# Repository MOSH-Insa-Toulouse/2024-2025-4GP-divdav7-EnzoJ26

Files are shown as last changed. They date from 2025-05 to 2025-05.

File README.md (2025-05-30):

2024-2025-4GP-HILLAH-JACQUET
---
## Sommaire 
   - [I) Contexte et objectifs du projet](#I-Contexteetobjectifsduprojet)
   - [II) Capteur à base de crayon graphite](#II-Capteuràbasedecrayongraphite)
   - [III) Electronique Analogique](#III-Electroniqueanalogique)
   - [IV) KiCad et PCB](#IV-KiCadetPCB)
   - [V) Arduino](#V-Arduino)
   - [VI) Application Mobile](#VI-ApplicationMobile)
   - [VII) Banc de Test](#VII-BancdeTest)
   - [VIII) Datasheet](#VIII-Datasheet)

---

## I) Contexte et objectifs du projet

L'objectif de ce projet est de réaliser un capteur low-tech à base de graphite sachant que les recherches ont démontré les nombreux avantages de l'utilisation de ce matériau. L’électronique à base de papier gagne en popularité parmi les ingénieurs grâce à sa facilité d’approvisionnement, sa simplicité de fabrication et son faible coût.<br>
Pour ce faire, nous avons mis en place la réalisation de tous les processus de fabrication d'un shield PCB que nous avons ensuite connecté à une carte Arduino.<br>
Notre PCB contient 6 composants différents : une jauge de contrainte, un flex sensor, un écran oled, un encodeur rotatoire, un potentiomètre digital et un module Bluetooth. À noter que nous n'avons pas utilisé le servo-moteur qui faisait partie des composants disponibles à implémenter.<br>
La carte Arduino fonctionne avec un code que nous avons implémenté en s'inspirant grandement des codes qui étaient disponibles en open-source.<br>
Nous avons ensuite réalisé une application mobile connectée au module bluetooth afin d'acquérir les données renvoyées par nos capteurs sur le téléphone.<br>
Nous avons évalué le capteur sur un banc de test avant de conclure par la datasheet de notre capteur.<br>
À la fin de la lecture de ce github, vous devriez savoir quel capteur choisir entre le graphite et le flex ;) . <br>

# Livrables

- PCB shield pour arduino uno <br>
- Code arduino <br>
- Banc de test du capteur <br>
- Application android qui fonctionne par bluetooth <br>
- Datasheet <br>

# Matériel utilisé

-Résistances: 1x1kΩ, 1x10kΩ, 2x100 kΩ, 1x47kΩ <br>
-Potentiomètre digital MCP41050 <br>
-Capacités: 3x100nF et 1x1µF <br>
-Arduino Uno <br>
-Capteur graphite à partir d'un support papier et d'un crayon <br>
-Flex Sensor <br>
-Encodeur rotatoire Keyes KY-040 <br>
-Ecran OLED 128x64 <br>
-Module Bluetooth HC-05 <br>
-Amplificateur opérationnel LTC1050 <br>

## II) Capteur à base de crayon graphite

Ce capteur low-tech utilise la théorie de la percolation au sein d’un système granulaire constitué de nanoparticules de graphite.<br>
Nous déposons une fine couche de graphite sur la feuille de papier ce qui présente un réseau percolé caractéristique. Dans ce réseau, le transport des électrons entre les nanoparticules est basé sur le mécanisme de l’effet tunnel.<br>
Lors de l'application de déformations en tension, le réseau percolé se trouve directement étendu. Cette déformation entraîne une augmentation de la distance effective entre les particules de graphite au sein du réseau. Une partie des chemins de percolation sont par conséquent rompus. Ainsi, la conduction du matériau diminue, donc la résistance de la couche de graphite augmente.<br>
Inversement, lors de l’application de déformations en compression, le réseau percolé se trouve directement comprimé. Cette déformation entraîne une diminution de la distance effective entre les particules.<br> 
Ainsi, de nouveaux chemins de percolation sont créés, la conduction du matériau augmente, soit la résistance de la couche de graphite diminue.

Voici un schéma explicatif de ces phénomènes:

<p align="center">
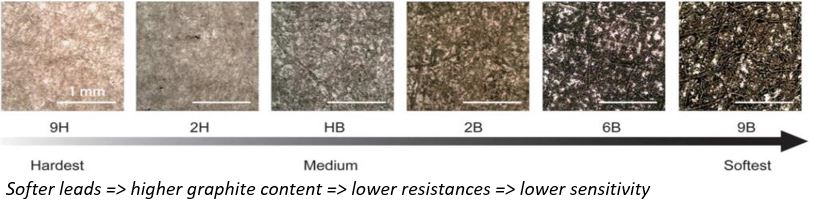
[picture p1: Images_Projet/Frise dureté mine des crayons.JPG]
Frise des duretés

<br>
<i>Sensibilité et Résistance en fonction de la dureté des mines</i>
</p>

Une jauge de contrainte est un circuit résistif dont la résistance varie en fonction de sa déformation. Donc en mesurant les variations de résistance de la jauge, nous en avons déduit la contrainte et la déformation appliquées.<br>
Notre jauge de contrainte est alimentée par une tension régulée de 5V d'une carte Arduino UNO.
<br>
Voici ci dessous le schéma d'un modèle de capteur graphite. Dans notre projet, nous avons utilisé les crayons de dureté 2H ; 2B ; HB.

<p align="center">
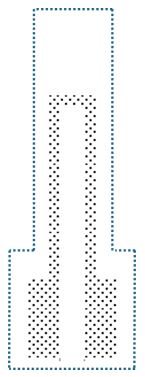
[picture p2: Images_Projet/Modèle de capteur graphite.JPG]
Figure 1 - Capteur à jauge de contrainte à base de crayon graphite

<br>
<i>Capteur à jauge de contrainte à base de crayon graphite</i>
</p>

## III) Electronique Analogique

Ce capteur graphite possède une résistance variable de l'ordre du GΩ. Le courant généré lorsque l'on applique une tension de 5V aux bornes du capteur est très faible.<br>
Pour obtenir un signal exploitable nous devions l'amplifier. Pour ce faire, nous avons utilisé un montage transimpédance constitué d'un amplificateur opérationnel.<br>
Pour cela nous avons dans un premier temps effectué une simulation électronique du capteur et de ce montage transimpédance sous LTSpice. Voici ci-dessous le montage réalisé sous LTSpice. Pour notre montage nous avons choisi l'AOP LTC1050 prenant en entrée un courant faible (de l'ordre d'une dizaine de picoampère).

<p align="center">
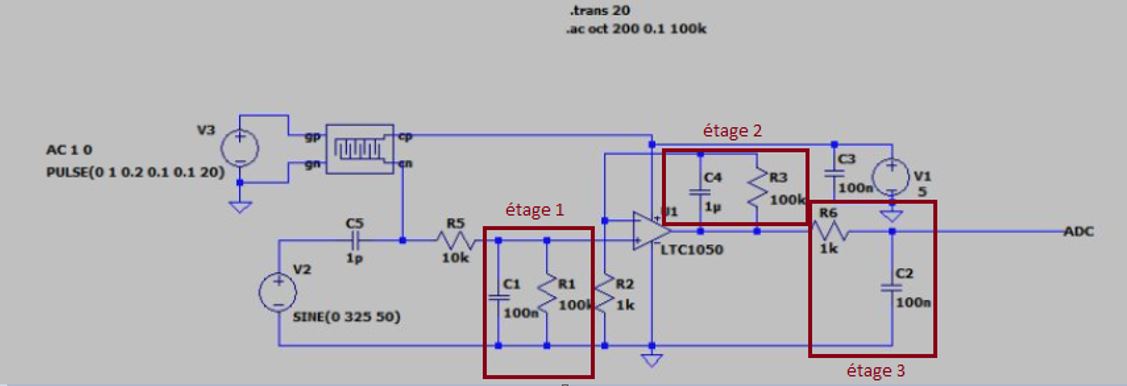
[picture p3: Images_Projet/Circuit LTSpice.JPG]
Circuit amplificateur réalisé dans LTSpice

<br>
<i>Circuit amplificateur réalisé dans LTSpice</i>
</p>
<br>
Ce circuit amplificateur contient 3 filtres passe bas passifs, dont nous avons pu tester le bon fonctionnement.<br>
<br>
- Le premier étage a une fréquence de coupure de 16 Hz, il permet de filtrer les bruits du courant en entrée. Nous avons testé ce premier étage pour vérifier que la fréquence de coupure soit la bonne.
<br>
</p>

<p align="center">
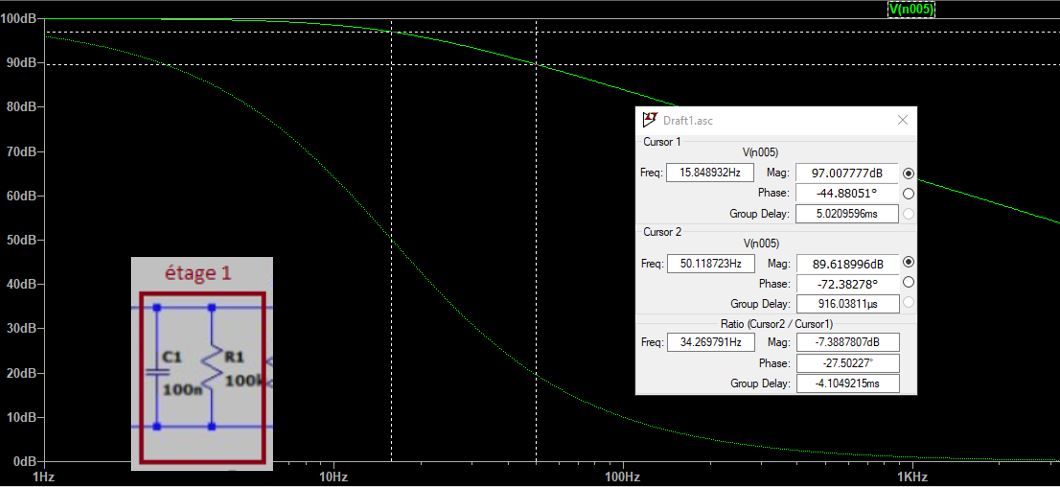
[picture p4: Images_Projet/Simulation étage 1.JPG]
Simulation de l'étage 1 dans LTSpice

<br>
<i>Simulation de l'étage 1 dans LTSpice</i>
</p>
En effet la fréquence de coupure est la bonne.
<br>
- Le second étage a une fréquence de coupure de 1,6 Hz. Il permet de filtrer la composante de bruit du réseau électrique: le bruit à 50 Hz.
<br>
</p>
<p align="center">
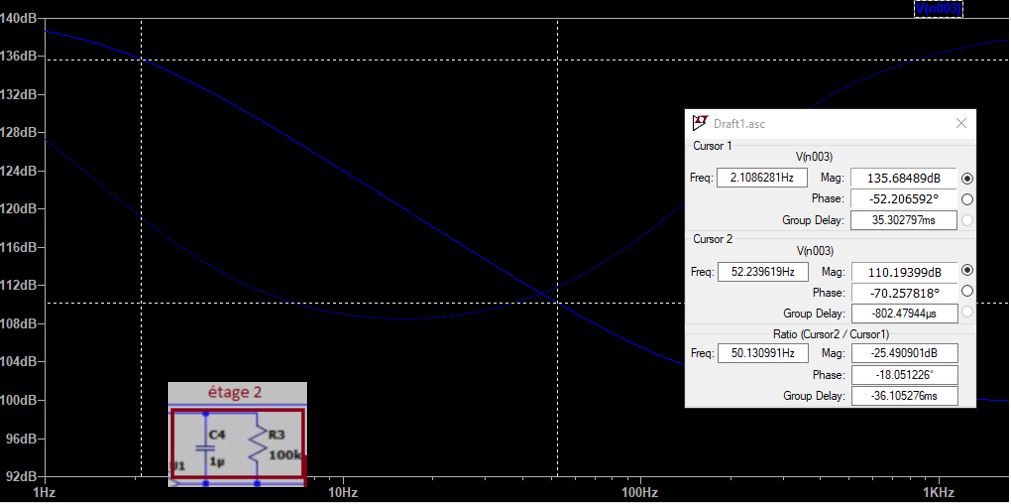
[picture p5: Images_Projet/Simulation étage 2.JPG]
Simulation de l'étage 2 dans LTSpice

<br>
<i>Simulation de l'étage 2 dans LTSpice</i>
</p>
La fréquence de coupure est de 2,1Hz alors que celle attendue est de 1,6Hz, ce qui reste dans les plages de fréquences attendues, donc nous la validons.
<br>
- Le dernier étage a une fréquence de coupure à 1,6 kHz qui permet d'atténuer le bruit provenant lors du traitement électronique.
<br>
</p>
<p align="center">
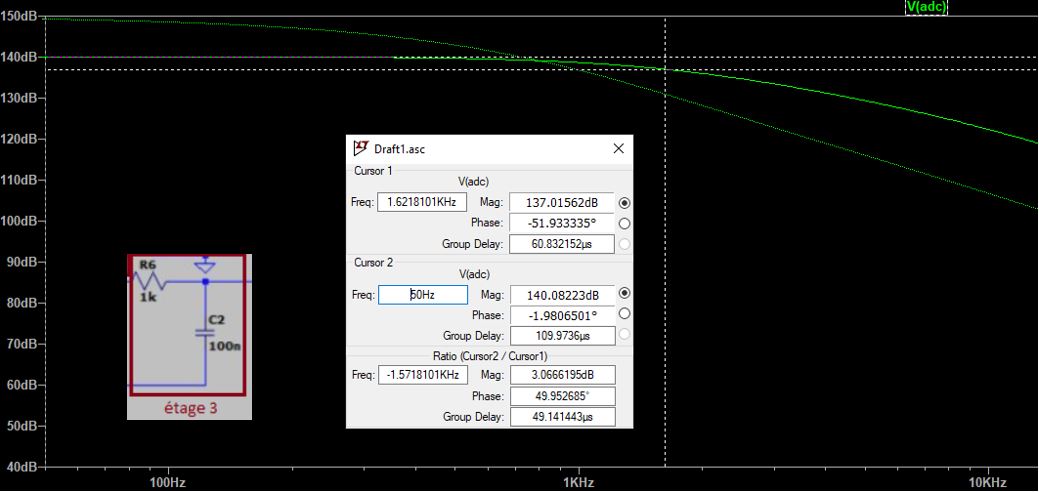
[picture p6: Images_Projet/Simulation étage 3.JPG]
Simulation de l'étage 3 dans LTSpice

<br>
<i>Simulation de l'étage 3 dans LTSpice</i>
</p>
En effet la fréquence de coupure est la bonne.
<br> 
Cette simulation nous permet de confirmer que l’arduino pourra bel et bien mesurer le signal de sortie car il sera d’environ 1V.

## IV) KiCad et PCB

Avant d'imprimer le PCB et de souder nos différents composants, nous avons dessiné les schémas électroniques, réalisé les composants électroniques et créé le PCB sur KICAD. Cette étape est importante car elle permet de prévisualiser le PCB, vérifier que tous les composants tiennent sur le PCB et ainsi de le sortir. Elle permet également de créer les différents routages de pistes. 

<p align="center">
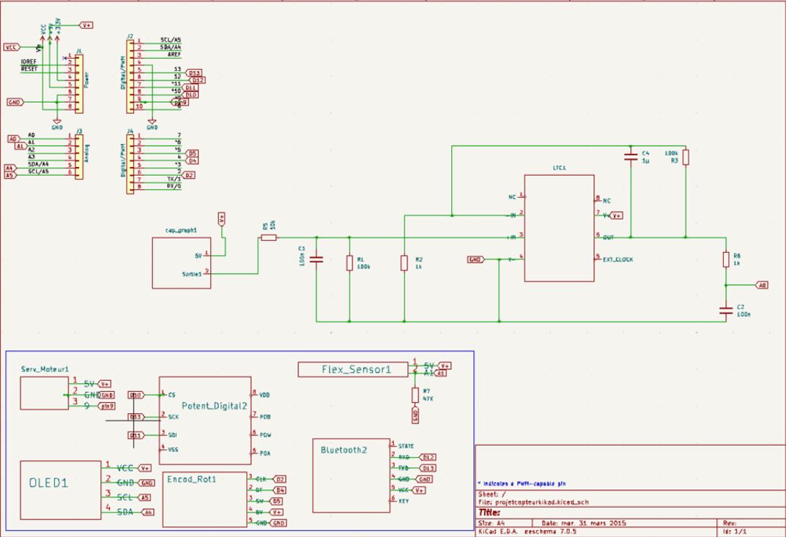
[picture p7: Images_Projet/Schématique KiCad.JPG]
Schémas électroniques

<br>
<i>Schémas électroniques</i>
</p>

<p align="center">
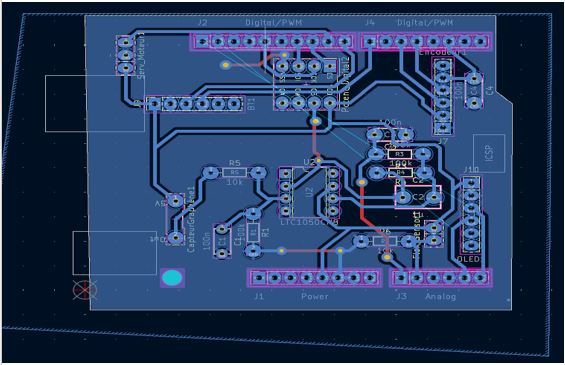
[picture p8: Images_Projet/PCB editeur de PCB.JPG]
Création du PCB et des différentes empreintes sur KiCad

<br>
<i>Création du PCB et des différentes empreintes sur KiCad</i>
</p>

<p align="center">
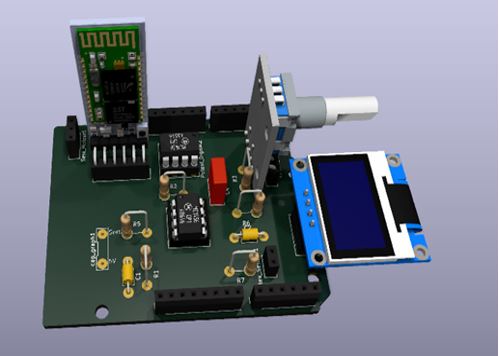
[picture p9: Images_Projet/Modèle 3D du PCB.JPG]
Visualisation 3D du PCB

<br>
<i>Visualisation 3D du PCB (idéale)</i>
</p>
<br>
Lorsque la disposition de nos différents composants électroniques était terminée suite au routage des pistes, nous avons pu imprimer le PCB, le percer et y souder les différents composants.
<br>
<br>
<p align="center">
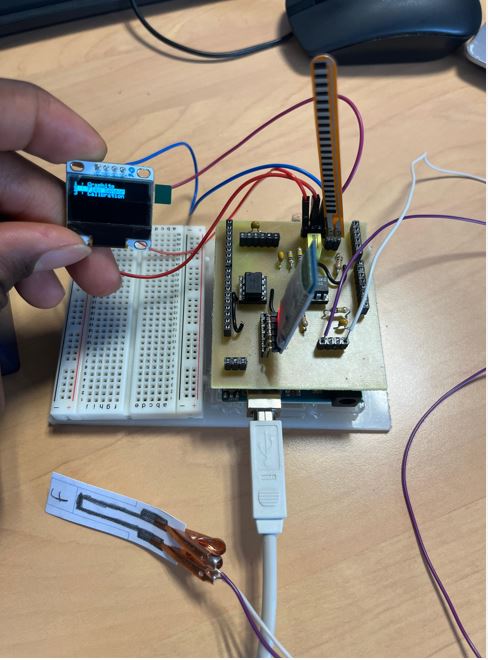
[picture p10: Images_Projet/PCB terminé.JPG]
PCB terminé

<br>
<i>PCB terminé</i>
</p>

Nous avons rencontré des problèmes lors de cette étape qui représentait une étape très importante du projet. Les librairies étaient assez complexes à retrouver et comme elles contenaient nos différentes empreintes cela nous a posé pas mal de problèmes dans notre gestion du temps, mais également dans la difficulté que l'on a éprouvé à en refaire.<br>
Au niveau du routage, il fallait optimiser la place présente sur le PCB tout en choisissant stratégiquement l'emplacement des différents modules. Cela n'a pas pu se faire sans la présence de 3 via. La visualisation 3D de notre PCB est bien celle qui découle de notre éditeur de PCB, mais c'était sans compter sur le fait que certains des modules que nous avions avaient leurs broches en déphasage avec les connexions disponibles présentes sur notre PCB (le module Bluetooth a une broche dans le vide et l'écran OLED se connecte de sorte à ne pas laisser la place au Flex Sensor de se connecter sur le PCB directement. Nous avons donc réfléchi à une solution filaire permettant de connecter l'écran OLED tout en le gardant à l'extérieur de la carte). Les autres modules n'ont pas de soucis de connexion.<br>
Nous avons solicité l'aide de Mr Grisolia et de Cathy particulièrement sur la partie empreintes et sur le routage. Nous les remercions de nous avoir débloqué plus d'une fois.

## V) Code Arduino

Le code Arduino permet la réception des mesures faites par les deux capteurs (Graphites et Flex Sensor) et d'afficher ces valeurs sur l'OLED. Pour cela nous nous sommes inspirés des codes disponibles en open-source. Du côté de l'application, bien qu'elle soit fonctionnelle sur la partie connexion au module bluetooth, elle ne trace pas le graphe de la variation de la résistance de nos capteurs en fonction de la déformation. En attendant de pouvoir déboguer le problème lié au code, nous avons donc pu effectuer nos mesures gräce à l'écran OLED et l'encodeur rotationnel qui permet de sélectionner le menu voulu par l'utilisateur. À noter l'utilisation d'un potentiomètre digital qui sert particulièrement à faire varier la valeur de la résistance R2 afin de mieux gérer notre gain. 
Notre programme principal est composé de sous programmes associés à ces éléments (à noter que nous ne nous sommes pas servis du servo-moteur dans ce projet):
<br>
<p align="center">
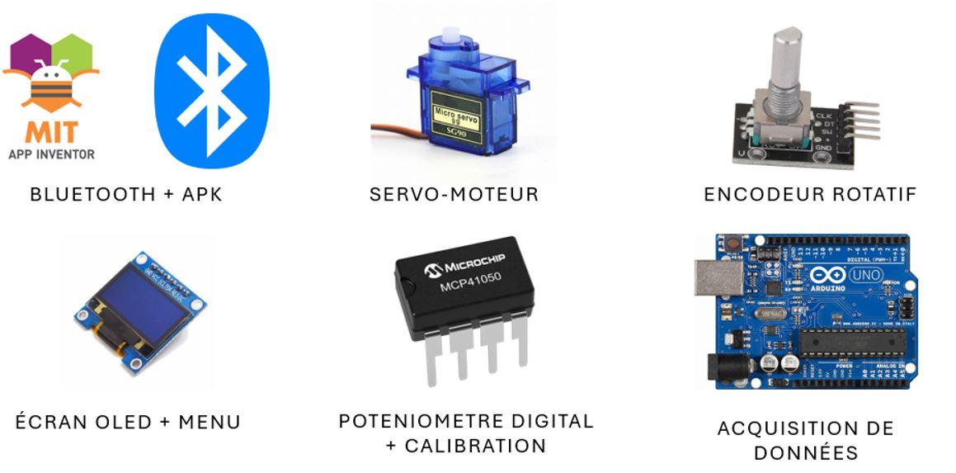
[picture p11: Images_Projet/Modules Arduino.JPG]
Figure 2 - Capteur à jauge de contrainte à base de crayon graphite

<br>
<i>Différents modules arduino</i>
<br>   

Les objectifs de la partie Arduino étaient d'acquérir les données de nos capteurs (résistance en fonction de la déformation), d'afficher nos mesures sur l'écran OLED via un menu déroulant contrôlé par l'encodeur et enfin, de communiquer avec l'application créée sous MIT APP Inventor. Ils ont été dans l'ensemble bien remplis.

## VI) Application mobile

Nous avons réalisé une application mobile sur le site MIT APP Inventor. <br>
Une fois que le module bluetooth est connecté au téléphone, nous pouvons acquérir les données des capteurs en temps réel et les tracer sur le graphe. 

<br> 
<p align="center">
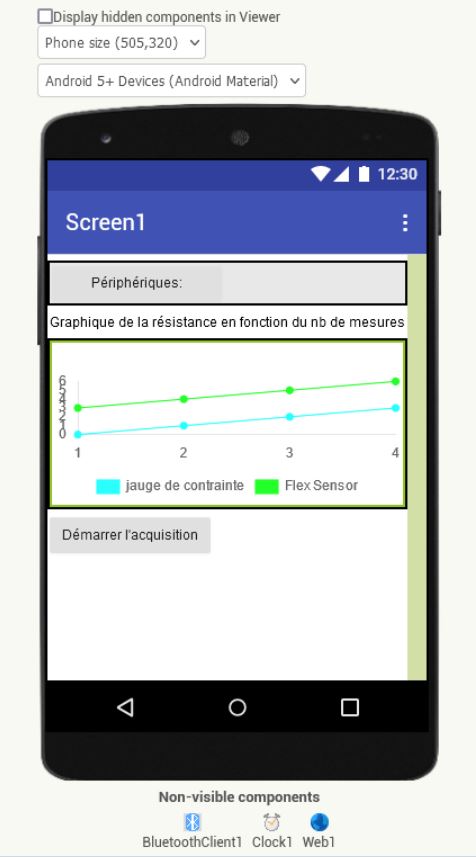
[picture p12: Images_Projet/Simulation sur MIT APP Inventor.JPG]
Simulation sur MIT APP Inventor

<br> 
<i>Aperçu MIT APP Inventor</i>
<br>
<p align="center">
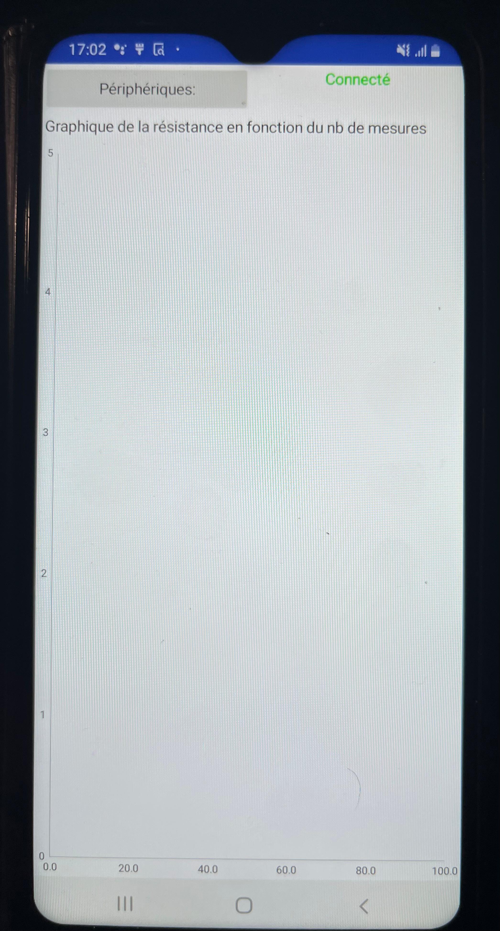
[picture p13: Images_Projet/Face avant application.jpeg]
Face avant de l'application

<br> 
<i>Face avant de l'application</i>
<br>
Malgré une application fonctionnelle sur la partie de recherche des périphériques et sur la connexion au HC-05, elle présente des limites sur le tracé de la variation de la résistance de notre capteur en fonction de la déformation qui y est appliquée. Comme détaillé lors de la partie précédente, en attendant de débuguer le problème, nous avons codé l'écran OLED pour qu'il nous affiche les valeurs d'intérêt.
   
## VII) Banc de tests

Nous avons relevé la variation de résistance de notre capteur en fonction de son angle de déformation. Pour cela, nous nous sommes servis de ce modèle de banc de test réalisé au FabLab, possédant pour chaque étage la même épaisseur, mais un diamètre différent. Nous disposions de 5 étages allant de 2 à 4 cm de diamètre avec un pas de 0,5cm entre chaque étage, tous étant épais de 0,2cm.
<br> 
<p align="center">
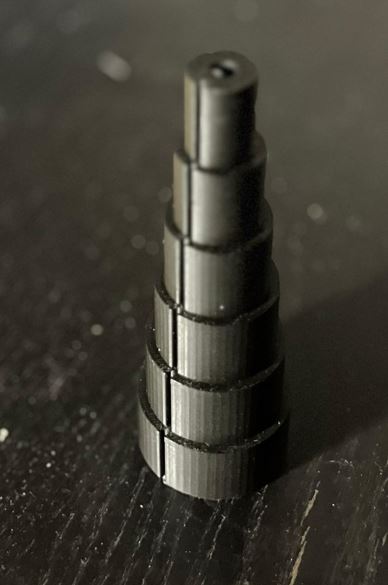
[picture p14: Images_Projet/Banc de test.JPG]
Banc de test

<br>
<i>Banc de test utilisé</i>
<br>
Les objectifs du banc étaient de pouvoir enregistrer les données, les traiter, les comparer avant de pouvoir concevoir et rédiger notre Datasheet.
   
## VIII) Datasheet

Nous avons déposé le PDF de la datasheet contenant une conclusion sur le choix de nos capteurs en fonction des résultats que nous avions obtenus que nous vous invitons à aller voir. Nous vous alertons sur le fait que nous avons donné un modèle linéaire aux différentes mesures que nous avons obtenu en compression et en tension, malgré le fait que les courbes de base ne soient pas linéaires. Les sensibilités que nous calculons sont obtenues en prenant en compte nos modèles linéaires. <br>

# Contacts
<br>
Si vous avez des questions sur ce projet, n'hésitez pas à contacter notre superbe duo (le binôme de l'année on a dit): 
<br>

David : hillah-a@insa-toulouse.fr
<br>
Enzo : ejacquet@insa-toulouse.fr

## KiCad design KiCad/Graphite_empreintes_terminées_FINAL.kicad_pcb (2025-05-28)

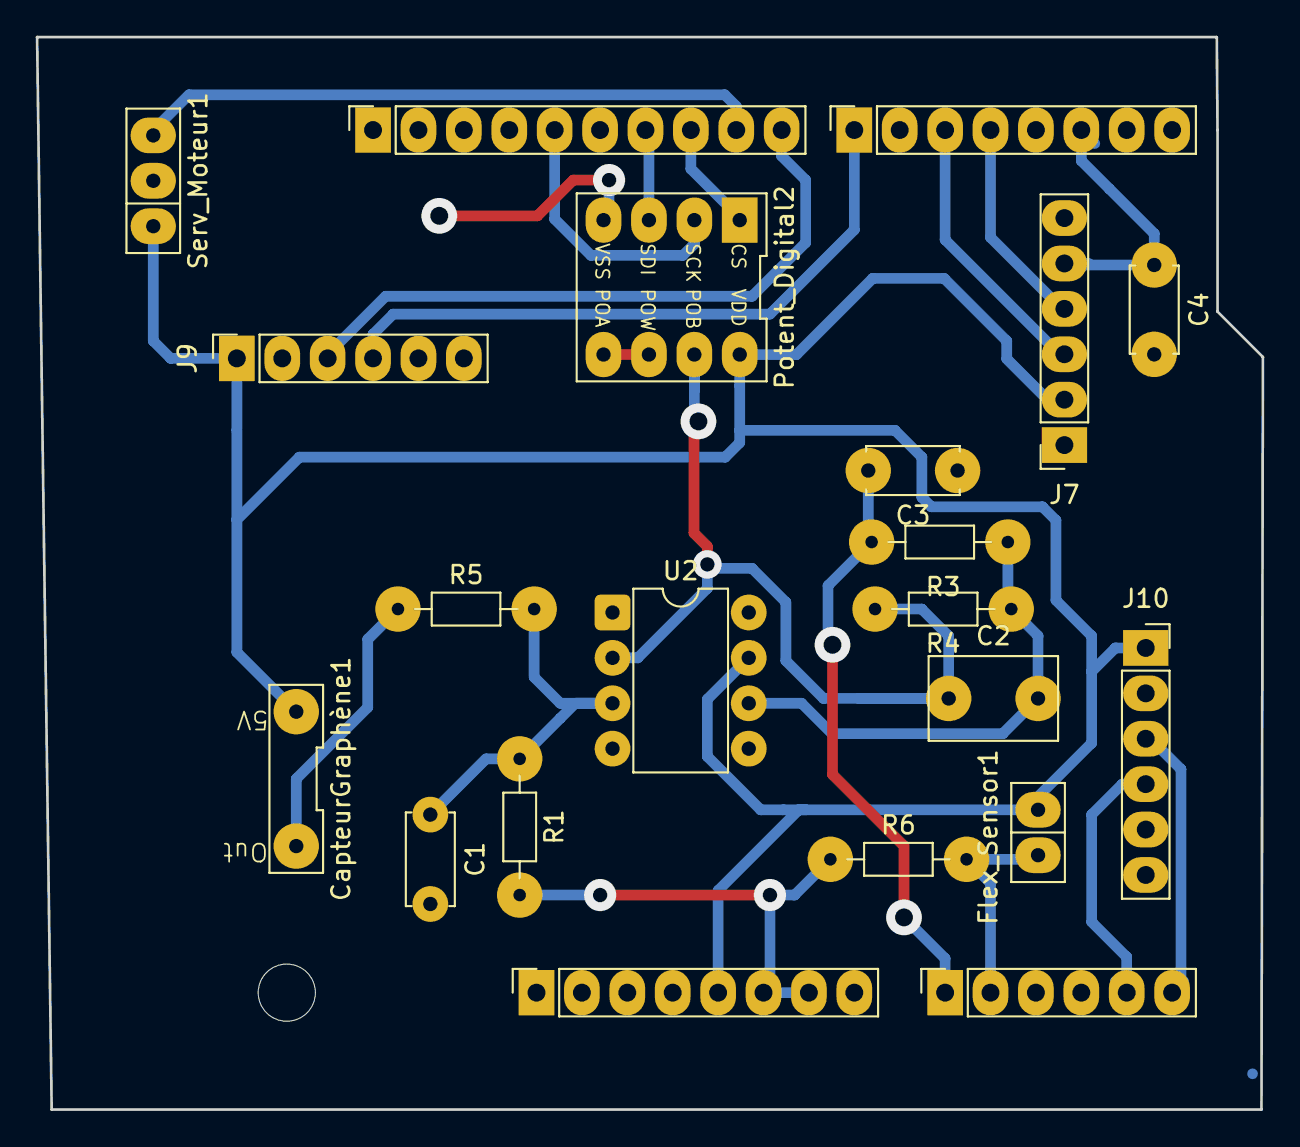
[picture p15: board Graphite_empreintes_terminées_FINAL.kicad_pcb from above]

Board: 2 copper layers, 68.6 x 60.0 mm, 22 parts (0 on the bottom side), 19 nets.

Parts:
C1, C3: 100n; C_Disc_D5.0mm_W2.5mm_P5.00mm
C2: 1µ; C_Rect_L7.0mm_W4.5mm_P5.00mm
C4: 100n; C_Disc_D4.7mm_W2.5mm_P5.00mm
CapteurGraphène1: capp_graph
Flex_Sensor1: SIP-2
J1: Power; PinSocket_1x08_P2.54mm_Vertical
J2: Digital/PWM; PinSocket_1x10_P2.54mm_Vertical
J3: Analog; PinSocket_1x06_P2.54mm_Vertical
J4: Digital/PWM; PinSocket_1x08_P2.54mm_Vertical
J7: Encodeur1; Bluetooth HC-05
J9: BT1; Bluetooth HC-05
J10: OLED1; Bluetooth HC-05
MH2: MountingHole_3.2mm
Potent_Digital2: Potentiometre_Digital3
R1, R3, R4: 100k; R_Axial_DIN0204_L3.6mm_D1.6mm_P7.62mm_Horizontal
R5, R6: 10k; R_Axial_DIN0204_L3.6mm_D1.6mm_P7.62mm_Horizontal
Serv_Moteur1: Servomoteur
U2: LTC1050CN8; DIP-8_W7.62mm

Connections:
5V: CapteurGraphène1.1 (5V), Flex_Sensor1.1 (5V), J1.5, J7.2 (GND), J9.1 (5V), J10.1 (5V), Potent_Digital2.8 (VDD), Serv_Moteur1.1 (5V), U2.7 (V+)
A1: Flex_Sensor1.2 (A1), J3.2, R6.2
AmpliOut: C3.2, J3.1, R3.2
CLK: C4.1, J4.6, J7.5
CS: J2.8, Potent_Digital2.1 (CS)
DATA: J4.4, J7.4 (Rx)
GND: C1.2, C3.1, C4.2, J1.6, J1.7, J2.4, J7.1 (5V), J9.2 (GND), J10.2 (GND), Potent_Digital2.4 (VSS), Potent_Digital2.5 (POA), Potent_Digital2.6 (POW), R1.2, R6.1, Serv_Moteur1.2 (GND), U2.4 (V-)
unnamed: CapteurGraphène1.2 (Out), R5.1
unnamed: C1.1, R1.1, R5.2, U2.3 (+IN)
unnamed: C2.2, R3.1, R4.1, U2.6 (OUT)
R2: C2.1, Potent_Digital2.7 (POB), R4.2, U2.2 (-IN)
RXD: J4.1, J9.4 (Rx)
SCK: J2.5, Potent_Digital2.2 (SCK)
SCL: J2.1, J3.6, J10.3 (Tx)
SDA: J2.2, J3.5, J10.4 (Rx)
SDI: J2.7, Potent_Digital2.3 (SDI)
SW: J4.3, J7.3 (Tx)
TXD: J2.10, J9.3 (Tx)
Vout_Servo: J2.9, Serv_Moteur1.3 (9)

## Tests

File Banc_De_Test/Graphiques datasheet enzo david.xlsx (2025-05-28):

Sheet: Tension
Diamètre(cm) | Epaisseur(cm) |  | R0 (Ω) |  | 2H | 2B | HB
2 | 0.02 | 2H | 20 | Déformation | R (Ω) | R (Ω) | R (Ω)
2.5 | 0.02 | HB | 960 | 0.01 | 25 | 1023 | 1023
3 | 0.02 | 2B | 423 | 0.008 | 20 | 1015 | 1002
3.5 | 0.02 |  |  | 0.006666666667 | 17 | 964 | 987
4 | 0.02 |  |  | 0.005714285714 | 15 | 776 | 910
 |  |  |  | 0.005 | 11 | 567 | 875
 |  |  |  | Déformation | ΔR/R0 (%) (2H) | ΔR/R0 (%) (2B) | ΔR/R0 (%) (HB)
 |  |  |  | 0.01 | 25 | 141.8439716 | 6.5625
 |  |  |  | 0.008 | 0 | 139.9527187 | 4.375
 |  |  |  | 0.006666666667 | -15 | 127.8959811 | 2.8125
 |  |  |  | 0.005714285714 | -25 | 83.45153664 | -5.208333333
 |  |  |  | 0.005 | -45 | 34.04255319 | -8.854166667
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

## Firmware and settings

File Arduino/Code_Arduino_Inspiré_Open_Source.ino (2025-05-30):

//Bluetooth
#include <SoftwareSerial.h>
#define rxPin 8 // Correspondant à la broche tx du module bluetooth
#define txPin 7 // Correspondant à la broche Rx du module bluetooth
#define baudrate 9600 
SoftwareSerial mySerial(rxPin ,txPin); //Definition du software serial


//OLED ATTENTION, la librarie utilisée (d'origine) consomme énormement de mémoire RAM en buffer.
// Si le programme ne lance rien, même pas le setup, le problème peut venir de là.
// On peut soit baisser le nombre de pixels dans l'écran, soit utiliser d'autres librairies moins gourmandes facilement trouvables sur internet.
#include <Adafruit_SSD1306.h>
#define nombreDePixelsEnLargeur 128        // Taille de l'écran OLED, en pixel, au niveau de sa largeur
#define nombreDePixelsEnHauteur 64        // Taille de l'écran OLED, en pixel, au niveau de sa hauteur
#define brocheResetOLED         -1          // Reset de l'OLED partagé avec l'Arduino (d'où la valeur à -1, et non un numéro de pin)
#define adresseI2CecranOLED     0x3C        // Adresse de "mon" écran OLED sur le bus i2c (généralement égal à 0x3C ou 0x3D)
Adafruit_SSD1306 ecranOLED(nombreDePixelsEnLargeur, nombreDePixelsEnHauteur, &Wire, brocheResetOLED);  


// MESURE Pin pour mesure de la tension du capteur //////////
const int capteurgraphitePin = A0;  // Pin A0
float calibre = pow(10,-6); // pour avoir des Mohms
// Variables pour éviter le delay 
unsigned long previousMillis = 0;        // will store last time LED was updated
// Variable pour cadencer l'acquisition
const long interval = 500;           // interval at which to blink (milliseconds) for MesureINST


// MESURE FLEX SENSOR
const int flexPin = A1;      // Pin connected to voltage divider output
const float VCC = 5;      // voltage at Ardunio 5V line
const float R_DIV = 10000.0;  // resistor used to create a voltage divider
const float flatResistance = 30000.0; // resistance when flat
const float bendResistance = 90000.0;  // resistance at 90 deg

//ENCODEUR ROTATOIRE
#define encoder0PinA  2  //CLK Output A Do not use other pin for clock as we are using interrupt
#define encoder0PinB  4  //DT Output B
#define Switch 5 // Switch connection if available

volatile int encoder0Pos = 1;

// Digital Potentiometer
#include <SPI.h>
const byte csPin           = 11;      // MCP42100 chip select pin
const int  maxPositions    = 256;     // wiper can move from 0 to 255 = 256 Positions
const long rAB             = 52200;   // 50k pot resistance between terminals A and B, mais pour ajuster au multimètre, je mets 47500
const byte rWiper          = 125;     // 125 ohms pot wiper resistance
const byte pot0            = 0x11;    // pot0 addr // B 0001 0001
const byte pot0Shutdown    = 0x21;    // pot0 shutdown // B 0010 0001
long R3;                              // Valeur de R3 calculé en sortir du potentiomètre
int PotPos;                           // Valeur de la position du potentiomètre entre 0 et 255



// MENU ///////////////////////////
int Position = 1; // Position par défaut dans le menu
int OK=0;  //Indicateur si SWITCH enclecnhé
String text1="1 : Graphite"; // Les différents menus
String text3="2 : Flex Sensor";
String text4="3 : Calibration";

// Permet de gérer le potentiomètre
void setPotWiper(int addr, int pos) {
  pos = constrain(pos, 0, 255);            // limit wiper setting to range of 0 to 255
  digitalWrite(csPin, LOW);                // select chip
  SPI.transfer(addr);                      // configure target pot with wiper Position
  SPI.transfer(pos);
  digitalWrite(csPin, HIGH);               // de-select chip

  R3 = ((rAB * pos) / maxPositions ) + rWiper; // Calcul de R3 (résistance entre wiper et B)
  Serial.print(F(" Resistance wiper to B terminal: "));
  Serial.print(R3);
}

void setup() {
    // Initialisation de l'écran OLED
  if(!ecranOLED.begin(SSD1306_SWITCHCAPVCC, adresseI2CecranOLED))
    while(1);   
  mySerial.begin(baudrate); // Initialiser le port bluetooth
  Serial.begin(baudrate); // Initialiser le port série
  pinMode(encoder0PinA, INPUT); 
  digitalWrite(encoder0PinA, HIGH);       // turn on pullup resistor

  pinMode(encoder0PinB, INPUT); 
  digitalWrite(encoder0PinB, HIGH);       // turn on pullup resistor

  pinMode(Switch,INPUT_PULLUP);

  attachInterrupt(0, doEncoder, RISING); // encoder pin on interrupt 0 - pin2

  Serial.begin (9600);

  digitalWrite(csPin, HIGH);        // chip select default to de-selected
  SPI.begin();
  delay(5000);
  PotPos=Calibration();             // Calibration du potentiomètre en fonction du capteur
}


void loop() {
  ChoixMenu(); // Affiche le menu et ses choix en boucle
}


void ChoixMenu(){
  // // MENU
  unsigned long currentMillis = millis ();
  if (currentMillis - previousMillis >= 500) 
  {
    previousMillis = currentMillis;
    ecranOLED.clearDisplay();                                   // Effaçage de l'intégralité du buffer
    ecranOLED.setTextSize(1);                           // Taille du texte
    ecranOLED.setCursor(0, 0);                          // Placement du texte
    ecranOLED.setTextColor(SSD1306_WHITE, SSD1306_BLACK);   // Couleur du texte, et couleur du fond
    //setPotWiper(pot0,7);
    Valider_Menu();
   // Fonction primordiale : vérifie si les boutons physiques ne sont pas appuyé et ajuste la variable position, OK et OK_TEL (si un bouton sur tél n'est pas cliqué)
    if(Position==1)                       // Si nous sommes en position 1, affiche le texte correspondant (effet de surbrillance)
    {
      ecranOLED.setTextColor(SSD1306_BLACK, SSD1306_WHITE);
      ecranOLED.println(text1);
      ecranOLED.setTextColor(SSD1306_WHITE, SSD1306_BLACK);
      ecranOLED.println(text3);
      ecranOLED.println(text4);
      ecranOLED.display();                            // Transfert le buffer à l'écran

      if (OK==1){
        OK=0;
        MesureINST();
      }
    
    }

    else if (Position==2)// Si nous sommes en position 3, affiche le texte correspondant (effet de surbrillance)
    {
      ecranOLED.println(text1);
      ecranOLED.setTextColor(SSD1306_BLACK, SSD1306_WHITE);
      ecranOLED.println(text3);
      ecranOLED.setTextColor(SSD1306_WHITE, SSD1306_BLACK); 
      ecranOLED.println(text4);
      ecranOLED.display();                            // Transfert le buffer à l'écran
      if (OK==1){
        OK=0;
        FlexSensor();
      }
     
    }
    else if (Position==3)// Si nous sommes en position 4, affiche le texte correspondant (effet de surbrillance)
    {
      ecranOLED.println(text1);
      ecranOLED.println(text3);
      ecranOLED.setTextColor(SSD1306_BLACK, SSD1306_WHITE); 
      ecranOLED.println(text4);
      ecranOLED.display();

      if (OK==1){
        OK=0;
        Calibration();
      }
         
    }
  }
}

void doEncoder() {
  if (digitalRead(encoder0PinA)==HIGH && digitalRead(encoder0PinB)==HIGH) {
    encoder0Pos++;
    Position=encoder0Pos;
    Serial.println (encoder0Pos, DEC);  //Angle = (360 / Encoder_Resolution) * encoder0Pos
  } else if (digitalRead(encoder0PinA)==HIGH && digitalRead(encoder0PinB)==LOW) {
    encoder0Pos--;
    Position=encoder0Pos;
    Serial.println (encoder0Pos, DEC);  //Angle = (360 / Encoder_Resolution) * encoder0Pos
  }
}



void FlexSensor(){
  int ADCflex;
  float Vflex;
  float Rflex;
  ecranOLED.clearDisplay();                                   // Effaçage de l'intégralité du buffer
  ecranOLED.setTextSize(1);                   // Taille des caractères (1:1, puis 2:1, puis 3:1)
  ecranOLED.setCursor(0, 0);
  ecranOLED.setTextColor(SSD1306_WHITE, SSD1306_BLACK);   // Couleur du texte, et couleur du fond
  ecranOLED.println(F("Mesure Flex Sensor:"));
  ecranOLED.display();    
  delay(1000);
  do
  {
  // Read the ADC, and calculate voltage and resistance from it
  ADCflex = analogRead(flexPin);
  Vflex = ADCflex * VCC / 1024.0;
  Rflex = R_DIV * (VCC / Vflex - 1.0); // Calcul de la résistance du flex
  // Use the calculated resistance to estimate the sensor's bend angle:
  // float angle = map(Rflex, flatResistance, bendResistance, 0, 90.0);
  // Serial.println("Bend: " + String(angle) + " degrees");
  delay(500);
  DisplayAndTransmitter(Rflex,3);
  Valider_Menu();
  }while (Position==2);
  
     
  ecranOLED.clearDisplay();                                   // Effaçage de l'intégralité du buffer
  ecranOLED.setCursor(0, 0);
  ecranOLED.setTextSize(1);
  ecranOLED.setTextColor(SSD1306_WHITE, SSD1306_BLACK);   // Couleur du texte, et couleur du fond                 
  ecranOLED.println(text1);
  ecranOLED.setTextColor(SSD1306_BLACK, SSD1306_WHITE);
  ecranOLED.println(text3);
  ecranOLED.setTextColor(SSD1306_WHITE, SSD1306_BLACK); 
  ecranOLED.println(text4);
  ecranOLED.display();
  delay(1000);
}


void MesureINST()
{
  float R4=100000;
  int Vcc=5;
  float R2=100000;
  int R1=10000;
  float Vadc=0;
  float Res=-1;
  // Affichage de mesureINST avant les mesures réelles, comme cela, l'utilisateur peut arrêter d'appuyer sur le bouton OK et cela évite de le faire sortir du programme
  ecranOLED.clearDisplay();                                   // Effaçage de l'intégralité du buffer
  ecranOLED.setTextSize(1);                   // Taille des caractères (1:1, puis 2:1, puis 3:1)
  ecranOLED.setCursor(0, 0);
  ecranOLED.setTextColor(SSD1306_WHITE, SSD1306_BLACK);   // Couleur du texte, et couleur du fond
  ecranOLED.println(F("Mesure instantannee : "));
  ecranOLED.display();    
  delay(1000);
  do
  {    
    // MESURE
    unsigned long currentMillis = millis();
    if (currentMillis - previousMillis >= interval) {
      previousMillis = currentMillis;
      Vadc = analogRead(capteurgraphitePin)*5.0/1024.0; // Valeur lu en voltage sortant du capteur
      Res=(R2*(1+R4/R3)*(Vcc/Vadc)-R2-R1)*calibre; // Calcul de la résistance
      Serial.print("Vadc = ");
      Serial.println(Vadc*1024/5);
      DisplayAndTransmitter(Res,1); // Transmet la donnée à afficher à l'ordi, à l'écran et au bluetooth
      Valider_Menu();
      }
  }while(Position==1); 
  
  
  ecranOLED.clearDisplay();                                   // Efface l'intégralité du buffer
  ecranOLED.setCursor(0, 0);
  ecranOLED.setTextSize(1);                 
  ecranOLED.setTextColor(SSD1306_BLACK, SSD1306_WHITE);   // Couleur du texte, et couleur du fond
  ecranOLED.println(text1);
  ecranOLED.setTextColor(SSD1306_WHITE, SSD1306_BLACK);   // Couleur du texte, et couleur du fond
  ecranOLED.println(text3);
  ecranOLED.println(text4);
  ecranOLED.display();    
  delay(1000);
 
} 

void DisplayAndTransmitter(float VALUE, int choix){
  char ResASCII[10];
  dtostrf(VALUE, 5, 2, ResASCII); //Transforme le float en chaîne de caractères
  ecranOLED.clearDisplay();                                   // Efface l'intégralité du buffer
  ecranOLED.setTextSize(1);                   // Taille des caractères (1:1, puis 2:1, puis 3:1)
  ecranOLED.setCursor(0, 0);
  ecranOLED.setTextColor(SSD1306_WHITE, SSD1306_BLACK);   // Couleur du texte, et couleur du fond
  if(choix==1){ecranOLED.println(F("Mesure instantanee :"));}
  else if(choix==2){ecranOLED.println(F("Mesure moyennee :"));}
  else if(choix==3){ecranOLED.println(F("Mesure Flex Sensor :"));dtostrf(VALUE, 5, 0, ResASCII);}
  else if(choix==4){ecranOLED.println(F("Calibration en cours"));}
  ecranOLED.setTextSize(3);                   // Ecris en gros
  ecranOLED.setCursor(0, 30); // Ecris à gauche de l'écran
  ecranOLED.print(ResASCII); // Envoyer sur l'écran la valeur
  mySerial.write(ResASCII); // Envoyer sur le port bluetooth la valeur acquise
  Serial.println(ResASCII); // Afficher sur le port série la valeur de la tension mesuré en bytes
  ecranOLED.display();                            // Transfert du buffer à l'écran
  delay(100);

}


void Valider_Menu(){
  if (digitalRead(Switch)==LOW){
    OK=1;
  }
}




//Calibration basée sur un principe de dichotimie. Essaie de se placer au centre de la plage des 1024 valeurs.
int Calibration(){
  ecranOLED.clearDisplay();                                   // Efface l'intégralité du buffer
  ecranOLED.setTextSize(1);                   // Taille des caractères (1:1, puis 2:1, puis 3:1)
  ecranOLED.setCursor(0, 0);
  ecranOLED.setTextColor(SSD1306_WHITE, SSD1306_BLACK);   // Couleur du texte, et couleur du fond
  ecranOLED.println(F("Calibration en cours"));
  ecranOLED.display();    
  delay(2000);   
  int Vadc=0;
  int tolerance=40; //Tolerance : 512+-20
  int V_Cible = 512;
  int a = 0;
  int b = 255;
  int ite=0;
  while(abs(Vadc - V_Cible) > tolerance)
  {
    Vadc=0;
    ite++;
    PotPos = (a + b)/2; // Prend le milieu  des 2 valeurs précédentes
    setPotWiper(pot0,int(PotPos));
    for(int i=0;i<3;i++)
    {
      Vadc += analogRead(capteurgraphitePin);
      delay(200);
    }
    Vadc = int(Vadc/3);
    Serial.print(F("Position Pota :"));
    Serial.print(PotPos);
    Serial.print(F(". Valeur lue :"));
    Serial.println(Vadc); // Afficher sur le port série la valeur de la tension mesuré en bytes
    DisplayAndTransmitter(PotPos,4);
    if(Vadc > V_Cible){ // on change le minimum ou le maximum
      a = PotPos;}
    else{
      b = PotPos;}
    if(ite>12){break;}
  }
  Serial.print(F("Finie. Pota en "));
  Serial.println(PotPos); // Afficher sur le port série la valeur de la tension mesuré en bytes
  return PotPos;

}

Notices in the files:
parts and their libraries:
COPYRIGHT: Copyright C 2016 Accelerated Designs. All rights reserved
